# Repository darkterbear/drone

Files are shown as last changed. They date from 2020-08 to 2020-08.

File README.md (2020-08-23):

# drone

Drone project in collaboration with @nmadev.

## Goals
- [X] Build a functioning drone controlled by a Raspberry Pi flight computer
- [X] Control the drone over Bluetooth with a PC and/or Android client
- [ ] Fly the drone autonomously over predefined flight plans
- [ ] Autonomously land the drone using computer vision

More to come...

## Hardware
This section will update as we add more features to our drone.
- FC + ESC Stack: Mamba F405 Mk. 2 FC + Mamba F40 Mk. 2 ESC
- Flight Computer: Raspberry Pi 3 B
- Frame: 3D printed according to CAD files
- Motors: iFlight XING-E 2207 1800KV 6S
- Props: Gemfan Hurricane 51466 (5.1x4.66x3)
- Battery: 14.8V 1300mAh 100C 4S LiPo
- Battery Monitor: Readytosky LiPo Battery Voltage Tester & Low Voltage Buzzer
- XT60 to 5V USB Power Adapter

## System Schematic
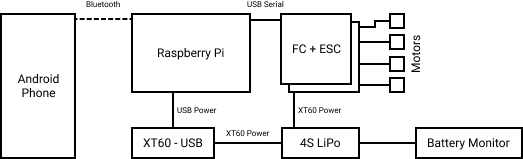
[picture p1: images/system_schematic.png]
System Schematic


## Betaflight FC Setup
This section is **very important**, and must be completed before running main.py or test-fc-command.py. This involves going to Betaflight Configurator and configuring the flight controller for use.

1. Download and install [Betaflight Configurator](https://github.com/betaflight/betaflight-configurator/releases) (on a system that is not your RPi, ideally).
2. Plug in the FC to that system, start Betaflight Configurator, select the appropriate serial port and hit "Connect"
3. In the left panel, go to "Configuration". 
4. In the "Receiver" section, select "MSP RX input (control via MSP port)". Click "Save and Reboot" and wait momentarily.
5. In the left panel, go to "Modes". 
6. In the "ARM" mode, click "Add Range", if there is no range already. 
7. In that range, select "AUX 1" as the channel, and 1400-1600 as the range. Click "Save".

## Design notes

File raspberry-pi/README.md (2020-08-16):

# Raspberry Pi

This subdirectory involves the code run on the Raspberry Pi to communicate with the flight controller.

## Prerequisites
- `python3`
- `pip3`

## Installation
- `pip3 install pyserial`
- `pip3 install bluedot`

## test-fc-telemetry.py
This script tests the serial connection between the RPi and the flight controller. If successful, this will output the FC attitude continuously.

1. Connect MSP/Betaflight flight controller to RPi or computer using USB or other serial port
2. Find the serial port that the flight controller is on (e.g. COM5, /dev/ttyUSB0, etc.)
3. In test-fc-telemetry.py, change the board declaration to use the serial port name: `board = MultiWii("[SERIAL PORT NAME HERE]")`
4. Run test-fc-telemetry.py for attitude output

## test-bluetooth.py
This script tests the Bluetooth connection between the RPi and the Android controller. If successful, this will output the RC commands sent by the Android controller.

1. Pair the RPi with the Android phone via Bluetooth
2. Run test-bluetooth.py
3. Open the Controller app
4. Select the Raspberry Pi in the app to initiate a connection
5. Once the dual d-pads appear, perform movements and observe commands outputted

## test-fc-command.py
**You must complete the Betaflight Configurator step in the root README before performing this, otherwise this will not work!** This script tests sending RC commands from the RPi to the FC using MSP. You need a voltmeter to perform this test.

1. Populate the serial port name in test-fc-command.py as done in steps 1-3 for test-fc-telemetry
2. Connect your voltmeter to your FC's output to the ESC; use GND and any ESC output
3. Run test-fc-command.py
4. The voltmeter should read ~54mV before arming, and ~71mV after arming. At the end, it should around ~80-90mV for medium throttle (1500)

## remote-control.py
Only attempt to run this if the prior tests all pass. This script will allow an Android mobile client to control this drone via Bluetooth.

1. Populate the serial port name in remote-control.py as done in steps 1-3 for test-fc-telemetry
2. Run remote-control.py
3. After at least 1 second, connect to this RPi in the Android client
4. After at least 6 seconds, the drone should be controllable with the Android client

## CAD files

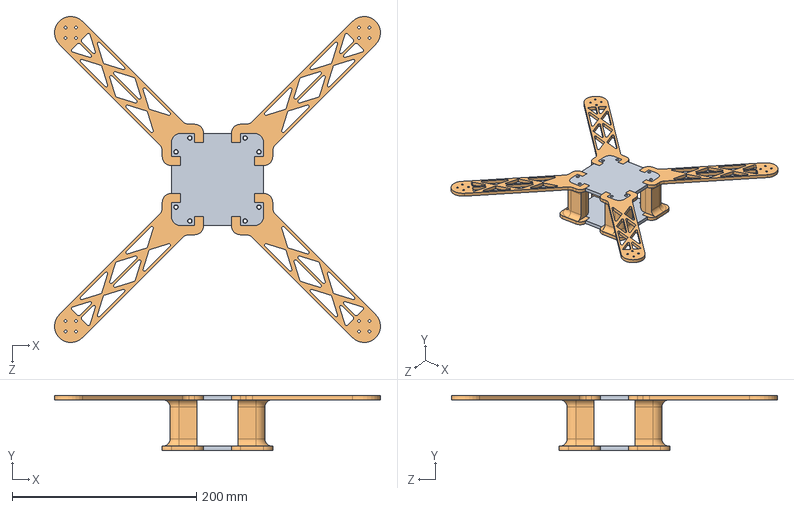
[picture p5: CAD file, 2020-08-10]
CAD/450Model/DroneAssembly.SLDASM
353.5 x 60.0 x 353.5 mm
ElectronicsPlates x 2
Arm x 4

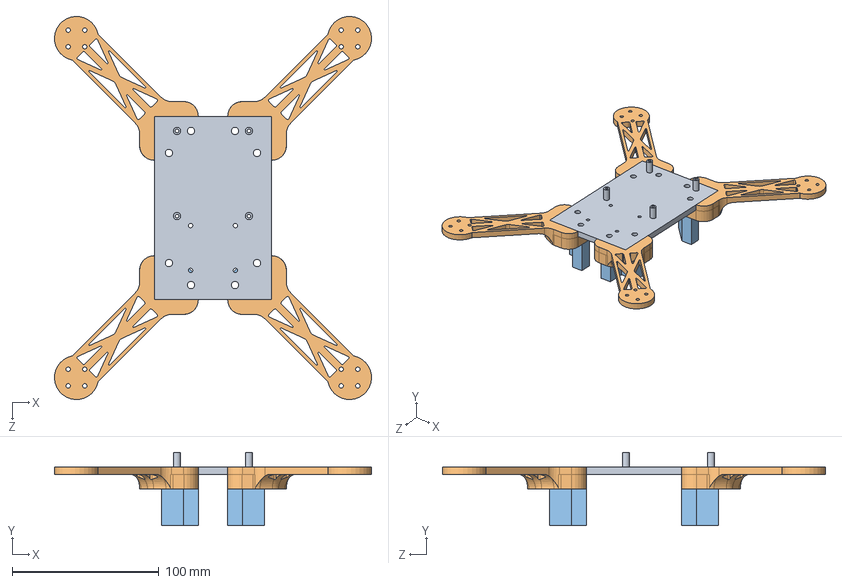
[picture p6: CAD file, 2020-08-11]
CAD/300Model/NewAssembly_1.SLDASM
216.0 x 50.0 x 261.0 mm
NewBasePlate
NewArm_1 x 4
VerticalSpacer x 4

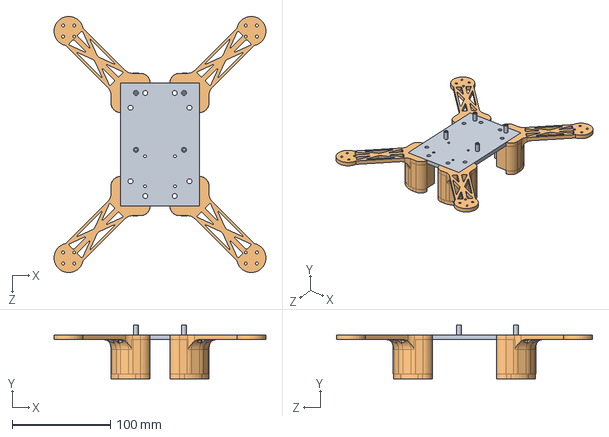
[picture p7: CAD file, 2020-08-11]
CAD/300Model/NewAssembly.SLDASM
216.0 x 55.0 x 261.0 mm
NewBasePlate
NewArm x 4

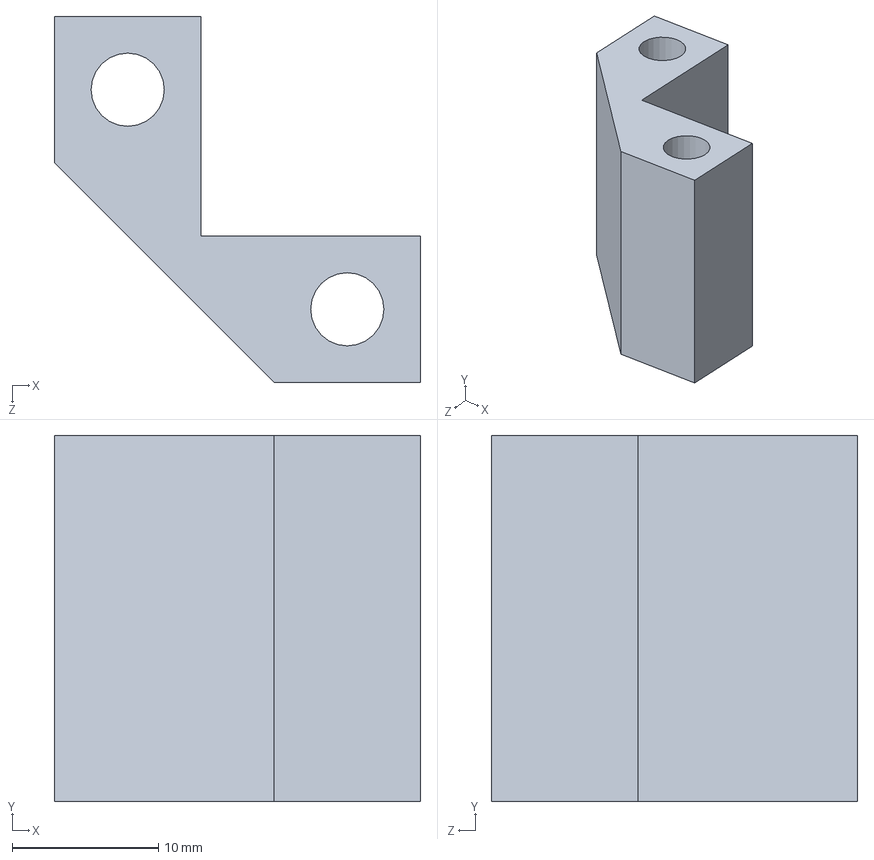
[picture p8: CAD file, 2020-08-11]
CAD/300Model/VerticalSpacer.SLDPRT
25.0 x 25.0 x 25.0 mm

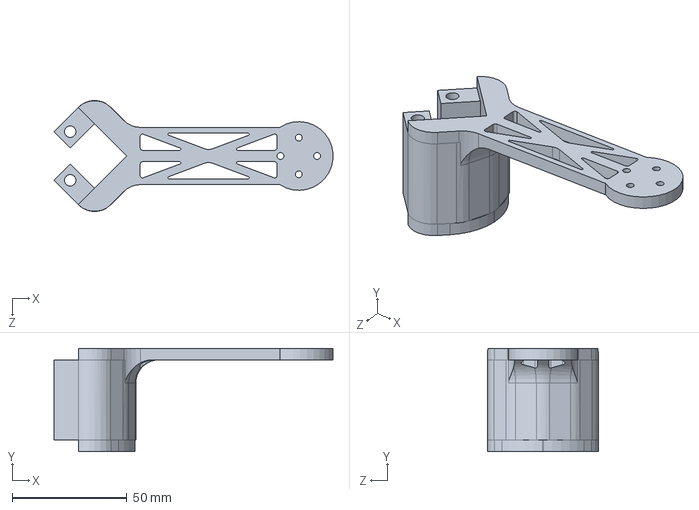
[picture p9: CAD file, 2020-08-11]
CAD/300Model/NewArm.SLDPRT
121.7 x 45.0 x 48.4 mm

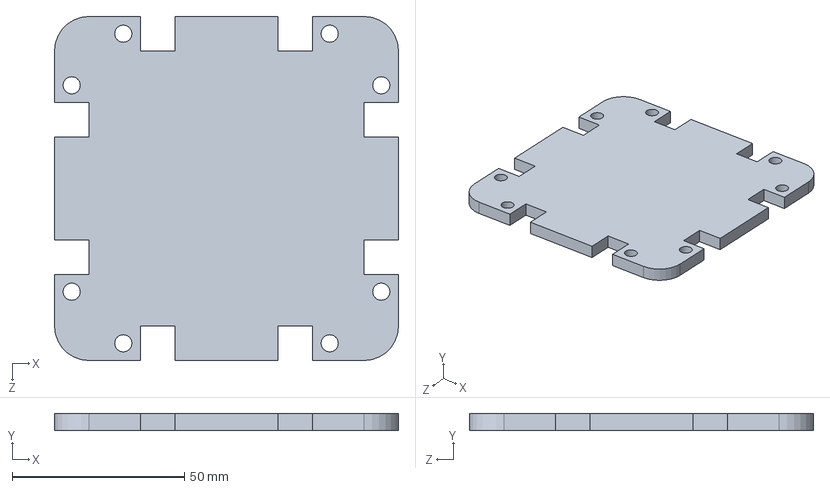
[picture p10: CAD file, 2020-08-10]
CAD/450Model/ElectronicsPlates.SLDPRT
100.0 x 5.00 x 100.0 mm

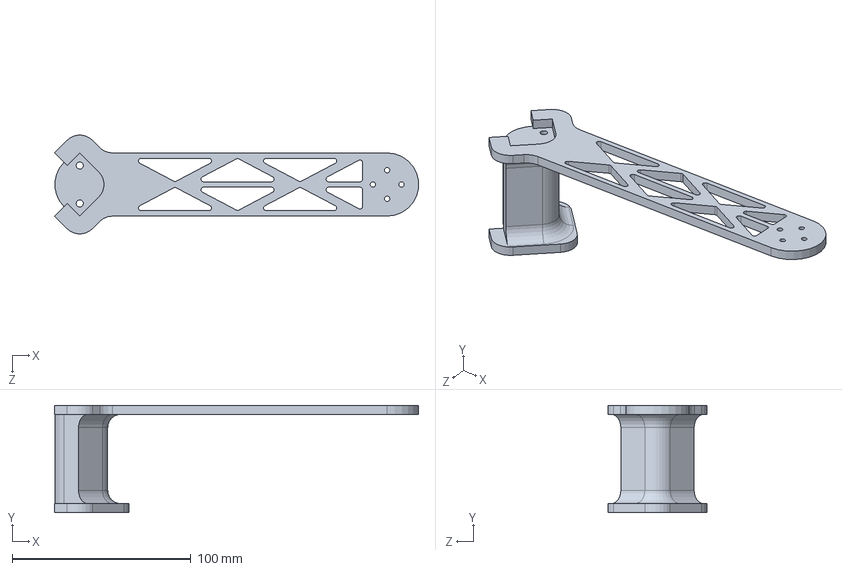
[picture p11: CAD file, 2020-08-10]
CAD/450Model/Arm.SLDPRT
203.7 x 60.0 x 55.2 mm

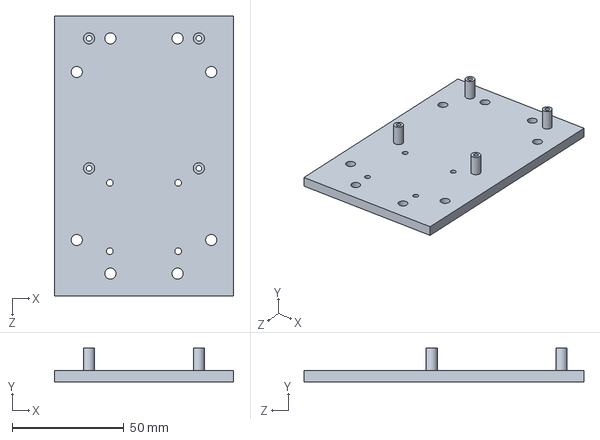
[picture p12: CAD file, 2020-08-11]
CAD/300Model/NewBasePlate.SLDPRT
80.0 x 15.0 x 125.0 mm

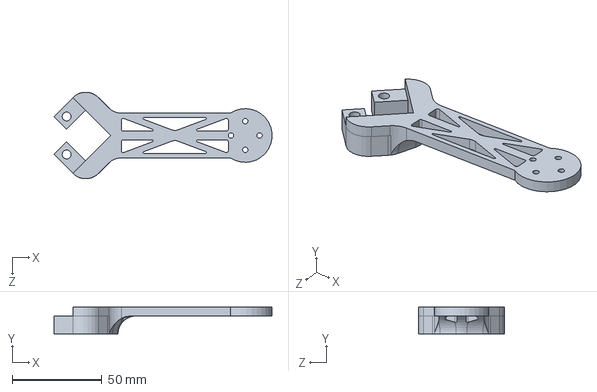
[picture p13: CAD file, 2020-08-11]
CAD/300Model/NewArm_1.SLDPRT
121.7 x 15.0 x 48.3 mm

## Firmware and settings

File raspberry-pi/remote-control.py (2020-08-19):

#!/usr/bin/env python

from msp import MultiWii
from bluedot import BlueDot
from util import push16
import time

board = MultiWii("/dev/ttyACM0")
print("Flight Controller connected!")

time.sleep(1.0)

leftStick = BlueDot(port=1)
rightStick = BlueDot(port=2)

while not leftStick.is_connected or not rightStick.is_connected:
    time.sleep(0.1)
print("Android Controller connected!")

board.enable_arm()
board.arm()


while True:
    # if Android remote disconnects, immediately end the program
    if not leftStick.is_connected or not rightStick.is_connected:
        break

    # calculate roll, pitch, yaw and throttle from dpad positions
    x, y = 0.0, -1.0
    if leftStick and leftStick.is_pressed:
        x, y = leftStick.position.x, leftStick.position.y
    throttle = (y + 1.0) / 2.0
    rudder = x

    x, y = 0.0, 0.0
    if rightStick and rightStick.is_pressed:
        x, y = rightStick.position.x, rightStick.position.y
    aileron = x
    elevator = y

    # roll, pitch, yaw, throttle, aux1, aux2, aux3, aux4
    # each from 1000 to 2000
    buf = []
    push16(buf, int(aileron * 500 + 1500))
    push16(buf, int(elevator * 500 + 1500))
    push16(buf, int(throttle * 1000 + 1000))
    push16(buf, int(rudder * 500 + 1500))
    push16(buf, 1500)
    push16(buf, 1000)
    push16(buf, 1000)
    push16(buf, 1000)

    # send rc command
    board.sendCMD(MultiWii.SET_RAW_RC, buf)
    time.sleep(0.025)

    # print board attitude
    board.getData(MultiWii.ATTITUDE)
    print(board.attitude)
    time.sleep(0.025)

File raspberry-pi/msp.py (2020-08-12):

#!/usr/bin/env python

"""multiwii.py: Handles Multiwii Serial Protocol."""

__author__ = "Aldo Vargas"
__copyright__ = "Copyright 2017 Altax.net"

__license__ = "GPL"
__version__ = "1.6"
__maintainer__ = "Aldo Vargas"
__email__ = "alduxvm@gmail.com"
__status__ = "Development"


import serial
import time
import struct
import util


class MultiWii:

    """Multiwii Serial Protocol message ID"""
    """ notice: just attitude, rc channels and raw imu, set raw rc are implemented at the moment """
    REBOOT = 68
    VTX_CONFIG = 88
    VTX_SET_CONFIG = 89
    ARMING_DISABLE = 99
    IDENT = 100
    STATUS = 101
    RAW_IMU = 102
    SERVO = 103
    MOTOR = 104
    RC = 105
    RAW_GPS = 106
    COMP_GPS = 107
    ATTITUDE = 108
    ALTITUDE = 109
    ANALOG = 110
    RC_TUNING = 111
    PID = 112
    BOX = 113
    MISC = 114
    MOTOR_PINS = 115
    BOXNAMES = 116
    PIDNAMES = 117
    WP = 118
    BOXIDS = 119
    RC_RAW_IMU = 121
    SET_RAW_RC = 200
    SET_RAW_GPS = 201
    SET_PID = 202
    SET_BOX = 203
    SET_RC_TUNING = 204
    ACC_CALIBRATION = 205
    MAG_CALIBRATION = 206
    SET_MISC = 207
    RESET_CONF = 208
    SET_WP = 209
    SWITCH_RC_SERIAL = 210
    IS_SERIAL = 211
    SET_MOTOR = 214
    EEPROM_WRITE = 250
    DEBUG = 254

    """Class initialization"""

    def __init__(self, serPort):
        """Global variables of data"""
        self.PIDcoef = {'rp': 0, 'ri': 0, 'rd': 0, 'pp': 0,
                        'pi': 0, 'pd': 0, 'yp': 0, 'yi': 0, 'yd': 0}
        self.rcChannels = {'roll': 0, 'pitch': 0, 'yaw': 0,
                           'throttle': 0, 'elapsed': 0, 'timestamp': 0}
        self.rawIMU = {'ax': 0, 'ay': 0, 'az': 0, 'gx': 0, 'gy': 0,
                       'gz': 0, 'mx': 0, 'my': 0, 'mz': 0, 'elapsed': 0, 'timestamp': 0}
        self.motor = {'m1': 0, 'm2': 0, 'm3': 0,
                      'm4': 0, 'elapsed': 0, 'timestamp': 0}
        self.attitude = {'angx': 0, 'angy': 0,
                         'heading': 0, 'elapsed': 0, 'timestamp': 0}
        self.altitude = {'estalt': 0, 'vario': 0, 'elapsed': 0, 'timestamp': 0}
        self.message = {'angx': 0, 'angy': 0, 'heading': 0, 'roll': 0,
                        'pitch': 0, 'yaw': 0, 'throttle': 0, 'elapsed': 0, 'timestamp': 0}
        self.vtxConfig = {'device': 0, 'band': 0,
                          'channel': 0, 'power': 0, 'pit': 0, 'unknown': 0}
        self.temp = ()
        self.temp2 = ()
        self.elapsed = 0
        self.PRINT = 1

        self.ser = serial.Serial()
        self.ser.port = serPort
        self.ser.baudrate = 115200
        self.ser.bytesize = serial.EIGHTBITS
        self.ser.parity = serial.PARITY_NONE
        self.ser.stopbits = serial.STOPBITS_ONE
        self.ser.timeout = 0
        self.ser.xonxoff = False
        self.ser.rtscts = False
        self.ser.dsrdtr = False
        self.ser.writeTimeout = 2
        """Time to wait until the board becomes operational"""

        while True:
            try:
                self.ser.open()
                time.sleep(1)
                break
            except Exception as error:
                time.sleep(0.1)

    """Function for sending a command to the board"""

    def sendCMD(self, code, data):
        data_length = len(data)
        data_format = str(data_length) + 'B' if data else ''
        checksum = 0
        total_data = ['$'.encode('utf-8'), 'M'.encode('utf-8'),
                      '<'.encode('utf-8'), data_length, code] + data
        for i in struct.pack('<2B' + data_format, *total_data[3:len(total_data)]):
            checksum = checksum ^ i
        total_data.append(checksum)
        try:
            b = None
            b = self.ser.write(struct.pack(
                '<3c2B' + data_format + 'B', *total_data))
        except Exception as error:
            print("\n\nError in sendCMD.")
            print("("+str(error)+")\n\n")
            pass

    """Function for sending a command to the board and receive attitude"""
    """
    Modification required on Multiwii firmware to Protocol.cpp in evaluateCommand:

    case MSP_SET_RAW_RC:
      s_struct_w((uint8_t*)&rcSerial,16);
      rcSerialCount = 50; // 1s transition
      s_struct((uint8_t*)&att,6);
      break;

    """

    def sendCMDreceiveATT(self, data_length, code, data):
        checksum = 0
        total_data = ['$'.encode('utf-8'), 'M'.encode('utf-8'),
                      '<'.encode('utf-8'), data_length, code] + data
        for i in struct.pack('<2B%dH' % len(data), *total_data[3:len(total_data)]):
            checksum = checksum ^ i
        total_data.append(checksum)
        try:
            start = time.time()
            b = None
            b = self.ser.write(struct.pack('<3c2B%dHB' %
                                           len(data), *total_data))

            while True:
                header = self.ser.read().decode('utf-8')
                if header == '$':
                    header = header+self.ser.read(2).decode('utf-8')
                    break
            datalength = struct.unpack('<b', self.ser.read())[0]
            code = struct.unpack('<b', self.ser.read())
            data = self.ser.read(datalength)
            temp = struct.unpack('<'+'h'*int(datalength/2), data)
            self.ser.flushInput()
            self.ser.flushOutput()
            elapsed = time.time() - start
            self.attitude['angx'] = float(temp[0]/10.0)
            self.attitude['angy'] = float(temp[1]/10.0)
            self.attitude['heading'] = float(temp[2])
            self.attitude['elapsed'] = round(elapsed, 3)
            self.attitude['timestamp'] = "%0.2f" % (time.time(),)
            return self.attitude
        except Exception as error:
            print("\n\nError in sendCMDreceiveATT.")
            print("("+str(error)+")\n\n")
            pass

    """Function to arm / disarm """

    def enable_arm(self):
        print('Enabling arming...')
        buf = []
        util.push8(buf, 0)
        util.push8(buf, 1)
        self.sendCMD(MultiWii.ARMING_DISABLE, buf)
        time.sleep(5.5)
        print('Arm protection off; arming is allowed')

    def arm(self):
        print('Arming...')
        # keep disarmed for 1s
        for _ in range(20):
            buf = []
            util.push16(buf, 1500)
            util.push16(buf, 1500)
            util.push16(buf, 1000)
            util.push16(buf, 1500)
            util.push16(buf, 1000)  # aux1 disarm position
            util.push16(buf, 1000)
            util.push16(buf, 1000)
            util.push16(buf, 1000)
            self.sendCMD(MultiWii.SET_RAW_RC, buf)
            time.sleep(0.05)
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

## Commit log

2020-08-09 Added starter raspberry pi code
2020-08-09 Update test.py serial port name and printing
2020-08-10 added some CAD for the general frame
    [Arm.SLDPRT, DroneAssembly.SLDASM, ElectronicsPlates.SLDPRT]
2020-08-10 Added system schematic image for README
2020-08-10 Added print to test-bluetooth
2020-08-10 Added throttle and rudder input calculations
2020-08-10 Fixes for raw throttle + yaw inputs
    [test-bluetooth.py]
2020-08-11 Wait for FC connected without thread
2020-08-11 Print FC attitude
2020-08-11 added some 300 mm part files
    [Arm.SLDPRT, DroneAssembly.SLDASM, ElectronicsPlates.SLDPRT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]
2020-08-12 Added reverse-engineered force-arm code
2020-08-12 Change sendCMD function and fc arm test
2020-08-12 More thorough test-fc-arm
2020-08-12 Added RC to fc-arm test
2020-08-12 Clean up arm disarm code
2020-08-19 Add Bluetooth signal loss failsafe
    [remote-control.py]
2020-08-19 Fixed input to RC translations
    [remote-control.py]
2020-08-23 Updated hardware schematic
